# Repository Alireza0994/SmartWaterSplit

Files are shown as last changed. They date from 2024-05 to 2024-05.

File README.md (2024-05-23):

# Overview

This project is a water splitting project that can used in water wells or other splitting systems that require a time-limiting system for use, a timer to limit the amount of usage and User Save and editing system.

This project has buzzer to have better user experience and uses a 16x2 character display and custom characters and animations for better User Interface.

this project controls a relay that can be used for triggering a contactor or starting a water pump that sucks the water of water well.
# Features and Description of Variables
The good Feature of this project are:

* You can register and edit people's data with a 4 by 4 Keypad
    > The Getting Data is:
    > * Phone number
    > * 4-digit Security Pin
    > * RFID tag data
    > * Limit day (Limitdow): the day of the week that the user allows to use water pomp
    > * Limit Start: the time that the user can use water
    > * Limit length: the hours of allowed usage of water  
    >
    >   > limit start > Allow zone > limit length  
    >   > 18:30       > Allow zone > 18:30 + 100 hours
    >   > this means for example the user can use water from 18:30 to 100 hours after this time // 100 hours after this time means the user is Allowed to use water from 18:30 to 100 hours (4 days and 4 hours). After this time or before Limit Start time, the user is not allowed to use water and the system accrues an error.
    > * Remaining Time: the Total Time of allowed usage of water (the user get this amount from the master. master can set the data of users and can recharge the total amount of Remain Time.    
    > ==***The Code of structure EEPRerson // stands for EEPROM Person:***==
    > ```cpp
    >   struct EEPerson {
    >       unsigned long rfid;         // 8 digits
    >       char phoneNumber[12];       // 12 digits
    >       int pinCode;                // 4 digits
    >       int dowLimit;               // 1 digit
    >       int limitStart;             // 4 digits
    >       int limitLength;            // 3 digits 
    >       unsigned long remainingTime;// 6 digits 
    >    };
    >    ```
* When you are starting the process of pump you can set a timer and after the timer runs out the system saves you time data to EEPROM and stops the process but won't stop the pump why?  

* When a customer stops the process we never turn the relay (pump) off cause if we continuously turn our pump on and off it can damage to our pump that is why I set a 2-minute timer in this 2 minute the pump is still on and the system waits for other people to start if no one enters a card and the 2 minute time runs out , we figure out we don't have anyone in queue and the pump will turn off.

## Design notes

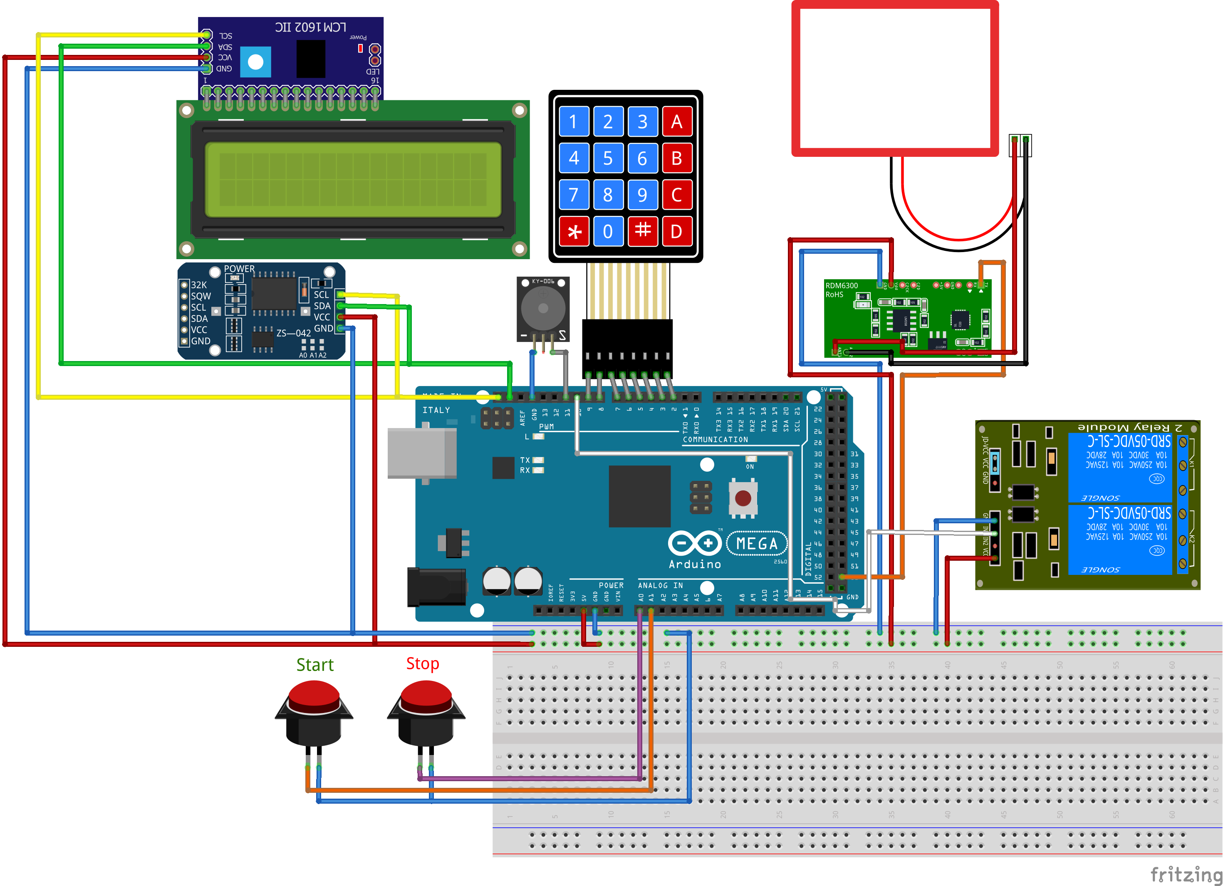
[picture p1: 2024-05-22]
Schematic.png

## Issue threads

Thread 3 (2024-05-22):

Passed Timer increase not correct

Alireza0994, 2024-05-22:

Closed 2024-05-22.

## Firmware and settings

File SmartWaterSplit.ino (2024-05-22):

/*
 ===================== program by Alireza Salehi Zadeh ==================
 ================================ 1403 / 3 / 2    =======================
 ================================    5 / 22/ 2024 ==========================
 keyword for finding section : $  dollor sign
 each person record takes 26 bytes | maximum people can fit in uno eeprom : 39
 wiring shcematic can be use in the program direcory
 this version is sipmpler coding style then first version
    so I tried to write less methods then last version
  Copyright 2024 by Alireza Salehi Zadeh
  Thankyou | i am happy to use git

*/

#include <LiquidCrystal_I2C.h> // for lcd
#include <Keypad.h>            // for keypad
#include <EEPROM.h>            // for EEPROM
#include <SoftwareSerial.h>    // for Radio Freaquency IDentification Serial * RFID
#include "RTClib.h"            // for Real Time Clock
int PompTriggerPin = 10;
#define btnStop  A0 //push button
#define btnStart A1 //push button
///////////////////////// Important ! ///////////////////////////////////
#define Master 12944421//Change if you want to replace you master card
long MasterID = Master;

#define RECORD_SIZE 38  // bytes
#define MAX_RECORDS 107  // maximum number of records
int NotFound = 404;
// تعریف پین‌های LCD
LiquidCrystal_I2C lcd(0x27, 16, 2); // Defining The Lcd 16X2 I2C with 0x27 i2c id
//========== Lcd Custome ICONS ========== 
  byte Horiz[8] = {
  0b00000,
  0b01010,
  0b01110,
  0b10001,
  0b00000,
  0b00000,
  0b00000,
  0b00000
  };
  byte horiz2[8] = {
  0b00000,
  0b00000,
  0b00000,
  0b00000,
  0b10001,
  0b01110,
  0b01010,
  0b00000
  };
  byte DoorOpen[8] {
  0b00000,
  0b01100,
  0b10010,
  0b10010,
  0b11110,
  0b11110,
  0b11110,
  0b00000
  };
  byte DoorClose[8] =
  {
  0b00000,
  0b01100,
  0b10010,
  0b10000,
  0b11110,
  0b11110,
  0b11110,
  0b00000
  };
  byte fan1[8] = {
  0b00000,
  0b00000,
  0b00100,
  0b01110,
  0b11111,
  0b01110,
  0b00100,
  0b00000
};
byte fan2[8] = {

  0b00000,
  0b00000,
  0b10001,
  0b01110,
  0b01110,
  0b01110,
  0b10001,
  0b00000
};
//
//rfid
  const int BUFFER_SIZE = 14; // RFID DATA FRAME FORMAT: 1byte head (value: 2), 10byte data (2byte version + 8byte tag), 2byte checksum, 1byte tail (value: 3)
  const int DATA_SIZE = 10; // 10byte data (2byte version + 8byte tag)
  const int DATA_VERSION_SIZE = 2; // 2byte version (actual meaning of these two bytes may vary)
  const int DATA_TAG_SIZE = 8; // 8byte tag
  const int CHECKSUM_SIZE = 2; // 2byte checksum
  long LastTag;
  unsigned long LastTagTime;
  SoftwareSerial ssrfid = SoftwareSerial(53,52); 

  uint8_t buffer[BUFFER_SIZE]; // used to store an incoming data frame 
  int buffer_index = 0;

//
// keypad
  const byte ROWS = 4;
  const byte COLS = 4;
  char keys[ROWS][COLS] = {
    {'1','2','3','A'},
    {'4','5','6','B'},
    {'7','8','9','C'},
    {'*','0','#','D'}
  };
  byte rowPins[ROWS] = {9, 8, 7, 6};
  byte colPins[COLS] = {4, 5, 3, 2};
  Keypad keypad = Keypad( makeKeymap(keys), rowPins, colPins, ROWS, COLS );
//
//Real Time Clock
  

  RTC_DS1307 rtc;


// EEPerson
struct EEPerson {
    unsigned long rfid;         // 8 digits
    char phoneNumber[12];       // 12 digits
    int pinCode;                // 4 digits
    int dowLimit;               // 1 digit
    int limitStart;             // 4 digits
    int limitLength;            // 3 digits 
    unsigned long remainingTime;// 6 digits 
};
//flags and variables
  bool canShowMainForm = true;
  EEPerson CurrentPerson;
  bool programMode;
  unsigned long millisMainFormShowed = 0;
  bool PompState = false;
  bool isrunning = false;
  bool AnimationFlag;
  unsigned long millisAnimation = 0;
  DateTime now;
  bool UserStarts;
  unsigned long pastMinutes = 0;
  int lastMinute;
  bool FirstTimeCheck = true;
  int readResult = 0; // save the address of Current Person on EEPROM 
  bool BackupGetted = false;
  unsigned long Timer = 0;
  int QueueTimer = 120;
  bool QueueTimerState = false;
  int lastSecend = 0;
  bool HasTimer = false;
EEPerson getInput(EEPerson UpdatePerson , bool SaveState = false, int Address = -1);
void AddUser(EEPerson person , bool SaveState = false , int Address = -1);
void setup() {
  InitLcd();
  Serial.begin(9600);
  InitPins();
  InitRFID();
  initrtc();
}

void loop() {
  
  LoopRFID();
  //check for Stop The Process by end of Remaining Time or limitlength
  if(UserStarts)
    CheckTime();
  //time checking 
  if(UserStarts && lastMinute != now.minute()){
    if(!FirstTimeCheck){
      pastMinutes++;
      CurrentPerson.remainingTime--;
      if(HasTimer){ 
        Timer--;
        if(Timer == 0){
          HasTimer = false;
          lcd.clear();
          lcd.setCursor(0,0);
          lcd.print("   Stoping...");
          lcd.setCursor(0,1);
          lcd.print("  Timer Ended");
          delay(700);
          tone(11 , 600 , 500);
          delay(100);
          tone(11 , 500 , 400);
          delay(100);
          tone(11 , 800 , 500);
          lcd.clear();
          lcd.setCursor(0 , 1);
          UserStarts = false;
          HasTimer = false;
          QueueTimer = 120;
          QueueTimerState = true;
          pastMinutes = 0;
          lastSecend = now.second();
          EEPROM.put(readResult , CurrentPerson);
        }
      }
      Serial.println("Adding Minutes");
    }
    else{
      FirstTimeCheck = false;
      Log("First Time Check Changed");
      Log(String(lastMinute));
      Log(String(now.minute()));
    }
    lastMinute = now.minute();
  }
  if(now.second() != lastSecend && QueueTimerState && !UserStarts){
    QueueTimer--;
    if(QueueTimer == 0){
      QueueTimerState = false;
      lcd.clear();
      lcd.setCursor(0,0);
      lcd.print("   Stoping...");
      delay(700);
      tone(11 , 600 , 500);
      delay(100);
      tone(11 , 500 , 400);
      delay(100);
      tone(11 , 800 , 500);
      digitalWrite(PompTriggerPin, HIGH);
      PompState = false;
      QueueTimer = 120;
      pastMinutes = 0;
    }
    lastSecend = now.second();
  }
  //check for save in eeprom
  if(pastMinutes % 60 == 0 && pastMinutes != 0 && !BackupGetted){// every 60 minutes we save to eeprom
    Log("Save to eeprom");
    EEPROM.put(readResult, CurrentPerson);
    BackupGetted = true;
    lcd.clear();
    lcd.setCursor(0, 1);
    lcd.print(" -Backup Stored-");
    delay(1000);
  }else{
    if(pastMinutes % 60 != 0)
      BackupGetted = false;
  }
  //btn press checks
  if(BtnCheck(btnStop)){
    Log("btn stop pressed");
    if(UserStarts){
      lcd.clear();
      lcd.setCursor(0,0);
      lcd.print("   Stoping...");
      delay(700);
      tone(11 , 600 , 500);
      delay(100);
      tone(11 , 500 , 400);
      delay(100);
      tone(11 , 800 , 500);
      lcd.clear();
      lcd.setCursor(0 , 1);
      UserStarts = false;
      HasTimer = false;
      QueueTimer = 120;
      QueueTimerState = true;
      pastMinutes = 0;
      lastSecend = now.second();
      EEPROM.put(readResult , CurrentPerson);
      //TODO Check Saf To Stop and Timer 2 minuts
    }
  }
  if(BtnCheck(btnStart)){
    Log("btn start pressed");
  }
  //millis checks
    if(millis() - millisMainFormShowed >= 999){
      if(canShowMainForm){ 
        ShowMainForm();
        millisMainFormShowed = millis();
      }
    }
  //
  //Keypad Button Checks
    char key = keypad.getKey();
    if(key){
      beep();
      if(programMode && key == 'C'){
        if(!PompState){
          digitalWrite(PompTriggerPin, LOW);
          Log("Opening");
          lcd.setCursor(0,1);
          lcd.print("Opening");
          PompState = true;
        }else{
          digitalWrite(PompTriggerPin, HIGH);
          Log("Closing Pomp");
          lcd.setCursor(0,1);
          lcd.print("Closing");
          PompState = false;
        }
        delay(1000);
        lcd.clear();
        
      }
    }
  //
  //Handeling Animations
    lcd.setCursor(7, 0);
    if (PompState == true) {
      if(millis() - millisAnimation >= 500){
        if (AnimationFlag == 1) {
          lcd.write(byte(4));
          AnimationFlag = 0;
        } else {
          lcd.write(byte(5));
          AnimationFlag = 1;
        }
        millisAnimation = millis();
      }
    } else {
      lcd.print(" ");
    }
  }
//RFID Codes
  void InitRFID(){
  ssrfid.begin(9600);
  ssrfid.listen(); 
  Log("RFID INIT DONE");
  }
  void LoopRFID(){
     if (ssrfid.available() > 0){
      bool call_extract_tag = false;

      int ssvalue = ssrfid.read(); // read 
      if (ssvalue == -1) { // no data was read
        return;
      }

      if (ssvalue == 2) { // RDM630/RDM6300 found a tag => tag incoming 
        buffer_index = 0;
      } else if (ssvalue == 3) { // tag has been fully transmitted       
        call_extract_tag = true; // extract tag at the end of the function call
      }

      if (buffer_index >= BUFFER_SIZE) { // checking for a buffer overflow (It's very unlikely that an buffer overflow comes up!)
        Serial.println("Error: Buffer overflow detected!");
        return;
      }

      buffer[buffer_index++] = ssvalue; // everything is alright => copy current value to buffer

      if (call_extract_tag == true) {
        if (buffer_index == BUFFER_SIZE) {
          unsigned tag = extract_tag();
        } else { // something is wrong... start again looking for preamble (value: 2)
          buffer_index = 0;
          return;
        }
      }    
    }    
  }
  unsigned extract_tag() {
      uint8_t msg_head = buffer[0];
      uint8_t *msg_data = buffer + 1; // 10 byte => data contains 2byte version + 8byte tag
      uint8_t *msg_data_version = msg_data;
      uint8_t *msg_data_tag = msg_data + 2;
      uint8_t *msg_checksum = buffer + 11; // 2 byte
      uint8_t msg_tail = buffer[13];

      long tag = hexstr_to_value(msg_data_tag, DATA_TAG_SIZE);
      if(millis() - LastTagTime <= 2000 && tag == LastTag) return;

      long checksum = 0;
      for (int i = 0; i < DATA_SIZE; i+= CHECKSUM_SIZE) {
        long val = hexstr_to_value(msg_data + i, CHECKSUM_SIZE);
        checksum ^= val;
      }
      // Serial.println(millis());
      // Serial.println(LastTagTime);
      // Serial.println("------");
      Log("tag is :");
      Log(String(tag));
      CheckID(tag);
      LastTag = tag;
      LastTagTime = millis();
        // Serial.print("Extracted Tag: ");
        // Serial.println(tag);
        return tag;

  }

  long hexstr_to_value(char *str, unsigned int length) { // converts a hexadecimal value (encoded as ASCII string) to a numeric value
    char* copy = malloc((sizeof(char) * length) + 1); 
    memcpy(copy, str, sizeof(char) * length);
    copy[length] = '\0'; 
    // the variable "copy" is a copy of the parameter "str". "copy" has an additional '\0' element to make sure that "str" is null-terminated.
    long value = strtol(copy, NULL, 16);  // strtol converts a null-terminated string to a long value
    free(copy); // clean up 
    return value;
  }
//EEPROM Codes
  //EEPROM Codes  : Checking ID
    void CheckID(unsigned long ID){
      Log("Checking ID");
      readResult = readPersonById(ID, CurrentPerson);
      Log("result is:");
      Log(String(readResult));
      Log(String(CurrentPerson.rfid));
      if(ID == MasterID){
        programMode = !programMode;
        Log("programmer mode is ");
        Log(String(programMode));
        lcd.clear();
        lcd.setCursor(0, 1);
        lcd.print("program mode ");
        if(programMode)
          lcd.print("on");
        else
          lcd.print("off");
        tone(11 , 500 , 300);
        delay(500);
        lcd.clear();
        lcd.print("Ready For Scan");
      }else{
        if(programMode){
          if (readResult == NotFound) {
            //adding to eeprom
            EEPerson AddingPerson;
            AddingPerson = getInput(AddingPerson);
            if(AddingPerson.rfid == 403){
              lcd.clear();
              lcd.setCursor(0,0);
              lcd.print("----Canceled----");
              delay(700);
              lcd.clear();
              beep();
              return;
            }
            AddingPerson.rfid = ID;
            AddUser(AddingPerson);
          }else{
            Log("User Found");
            EEPerson UpdatingPerson;
            UpdatingPerson = CurrentPerson;
            UpdatingPerson = getInput(UpdatingPerson , true , readResult);
            if(UpdatingPerson.rfid == 403){
              lcd.clear();
              lcd.setCursor(0,0);
              lcd.print("----Canceled----");
              delay(700);
              lcd.clear();
              return;
            }
            UpdatingPerson.rfid = ID;
            AddUser(UpdatingPerson , true , readResult);
          }
        }else{
          //check for start
          if(readResult != NotFound){
          //   //lcdtype("Enter Pass:");
            Log("Found");
            canShowMainForm = false;
            lcd.clear();
            lcd.setCursor(0,0);
            lcd.print("Enter Password:");
            lcd.setCursor(0,1);
            String InputString = "";
            while(InputString.length() != 4){
              char key = keypad.getKey();
              if(key){
                beep();
                if(key == 'B'){
                  InputString.remove(InputString.length() - 1);
                  lcd.setCursor(InputString.length(), 1);
                  lcd.print(" ");
                  lcd.setCursor(InputString.length(), 1);
                }else{
                  InputString += key;
                  lcd.print("*");
                }
              }
            }
            Log("Password is:");
            Log(InputString);
            Log("Correct password is :");
            Log(String(CurrentPerson.pinCode));
            lcd.clear();
            lcd.setCursor(0,0);
            if(InputString.toInt() == CurrentPerson.pinCode){
              Log("True You can use");
              lcd.print("Password Correct :)");
              lcd.setCursor(0,1);
              lcd.print("welcome ");
              lcd.print(CurrentPerson.rfid);
              delay(700);
              lcd.clear();
              lcd.setCursor(0,0);
              lcd.print("Total: |B :back");
              lcd.setCursor(0,1);
              lcd.print(String(CurrentPerson.remainingTime / 60));
              lcd.print(":");
              lcd.print(String(CurrentPerson.remainingTime % 60));
              lcd.print("|D :Timer");
              char key;
              while (true) {
                key = keypad.getKey();
                if(BtnCheck(btnStart)){
                  CheckForStart();
                  return;
                }
                if(key){
                  beep();
                  if(key == 'D' || key == 'B')
                    break;
                }
              }
              Log("Key Getted");
              if(key == 'B'){
                lcd.clear();
                lcd.setCursor(0,0);
                lcd.print("----Canceled----");
                delay(700);
                lcd.clear();
                canShowMainForm = true;
                return;
              }
              if(key == 'D'){
                //timer
                canShowMainForm = false;
                lcd.clear();
                lcd.setCursor(0, 0);
                lcd.print("Enter Timer data:");
                lcd.setCursor(0, 1);
                lcd.print("     XXX:XX");
                lcd.setCursor(5, 1);
                lcd.blink();
                InputString = "";
                int i = 0;
                int Hours = 0;
                int Minuts = 0;
                int cx = 5;
                //getting hours
                while (i < 3) {
                    char key = keypad.getKey();
                    if (key && key != '#') {
                      beep();
                      if(key == 'B'){
                        InputString.remove(InputString.length()-1);
                        lcd.setCursor(--cx, 1);
                        lcd.print("X");
                        lcd.setCursor(cx, 1);
                        i--;
                      }else{
                        InputString += key;
                        lcd.print(key);
                        i++;
                        cx++;
                      }
                    }
                }
                Hours = InputString.toInt();
                InputString = "";
                lcd.setCursor(9 , 1);
                i = 0;
                cx = 9;
                //getting minutes
                while (i < 2) {
                    char key = keypad.getKey();
                    if (key && key != '#') {
                      beep();
                      if(key == 'B'){
                        InputString.remove(InputString.length()-1);
                        lcd.setCursor(--cx, 1);
                        lcd.print("X");
                        lcd.setCursor(cx, 1);
                        i--;
                      }else{
                        InputString += key;
                        lcd.print(key);
                        i++;
                        cx++;
                      }
                    }
                }
                Minuts = InputString.toInt();
                InputString = "";
                lcd.noBlink();
                Log(String(Hours));
                Log(":");
                Log(String(Minuts));
                lcd.clear();
                lcd.print("Press Start/Stop");
                lcd.setCursor(0, 1);
                lcd.print("================");
                while(true){
                  if(BtnCheck(btnStart)){
                    Timer = Hours * 60 + Minuts;
                    HasTimer = true;
                    CheckForStart();
                    return;
                  }
                  if(BtnCheck(btnStop)){
                    lcd.clear();
                    lcd.setCursor(0,0);
                    lcd.print("----Canceled----");
                    delay(700);
                    lcd.clear();
                    canShowMainForm = true;
                    return;
                  }
                }
              }
            }else{
              Log("False You can not use");
              lcd.print("Not Correct :(");
              canShowMainForm = true;
              delay(700);
              lcd.clear();
            }
          //   flags.NormalState = 1;
          //   flags.AddingState = 2;
          }
          //if readresult not 404 start timer or wait for confirm to start the timer
        }
      }
    }
  // EEPROM Codes : Checking for start pomp
    void CheckForStart(){
      int Time = now.hour() * 60 + now.minute();
      unsigned long fullTime = CurrentPerson.limitStart + CurrentPerson.limitLength * 60;
      // int from = CurrentPerson.limitStart;
      // int to = CurrentPerson.limitStart + CurrentPerson.limitLength;
      int fromDay = CurrentPerson.dowLimit;
      int toDay = fromDay + fromDay + (CurrentPerson.limitLength / 24 );
      int fromTime = CurrentPerson.limitStart;
      int toTime = (CurrentPerson.limitStart + (CurrentPerson.limitLength * 60)) - toDay * 24;

      //When the conditions are not ok we quit the method so when all is good blow codes will run
      if(CurrentPerson.remainingTime == 0){
        lcd.clear();
        lcd.setCursor(0,0);
        lcd.print("   Total is 0");
        lcd.setCursor(0,1);
        lcd.print(" Can not start :(");
        delay(1500);
        lcd.clear();
        canShowMainForm = true;
        return;
      }
      Log("now time is :");
      Log(String(Time));
      Log("limits start is :");
      Log(String(CurrentPerson.limitStart));
      Log("limits end is :");
      Log(String(toTime));
      Log("converted dow is :");
      Log(String(now.dayOfTheWeek() + 1));
      Log("from day is ");
      Log(String(fromDay));
      Log("to day is ");
      Log(String(toDay));
      if(CurrentPerson.dowLimit != 9){
        if(Time >= CurrentPerson.limitStart && Time <= toTime && (now.dayOfTheWeek() + 1) >= fromDay && (now.dayOfTheWeek() + 1) <= toDay){ 
          startProccess();
          return;
        }
        errorStartProccess();
        return;
      }
      else{
        startProccess();
        return;
      }
    }
    int CheckForStop(){ //return 0 => Can resume using of pomp | 1 => Remain Time is = 0 | 2 = limit time reached
      int Time = now.hour() * 60 + now.minute();
      unsigned long fullTime = CurrentPerson.limitStart + CurrentPerson.limitLength * 60;
      // int from = CurrentPerson.limitStart;
      // int to = CurrentPerson.limitStart + CurrentPerson.limitLength;
      int fromDay = CurrentPerson.dowLimit;
      int toDay = fromDay + fromDay + (CurrentPerson.limitLength / 24 );
      int fromTime = CurrentPerson.limitStart;
      int toTime = (CurrentPerson.limitStart + (CurrentPerson.limitLength * 60)) - toDay * 24;
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

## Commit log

2024-05-22 Solved The not checking for stop problem
    [SmartWaterSplit.ino]
2024-05-22 this update solves the formatting problem of Remain time and limit start screens
    [SmartWaterSplit.ino]
2024-05-22 i think this solved the counting problem
    [SmartWaterSplit.ino]
2024-05-22 Added Schematics : fritzing & png
    [Schematic.fzz]
